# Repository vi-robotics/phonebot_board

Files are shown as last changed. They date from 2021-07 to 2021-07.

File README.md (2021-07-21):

# phonebot_board

The main PhoneBot electrical board containing servo control, regulator, charging and wireless capability.

This repository consists of two main components: design and firmware. The design folder contains the KiCAD design files, and the firmare folder contains the firmware meant to run on the design. Relevant documentation is located in each folder's README.md

- [Design](/design/README.md)
- [Firmware](/firmware/README.md)

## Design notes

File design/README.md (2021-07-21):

# Phonebot Board

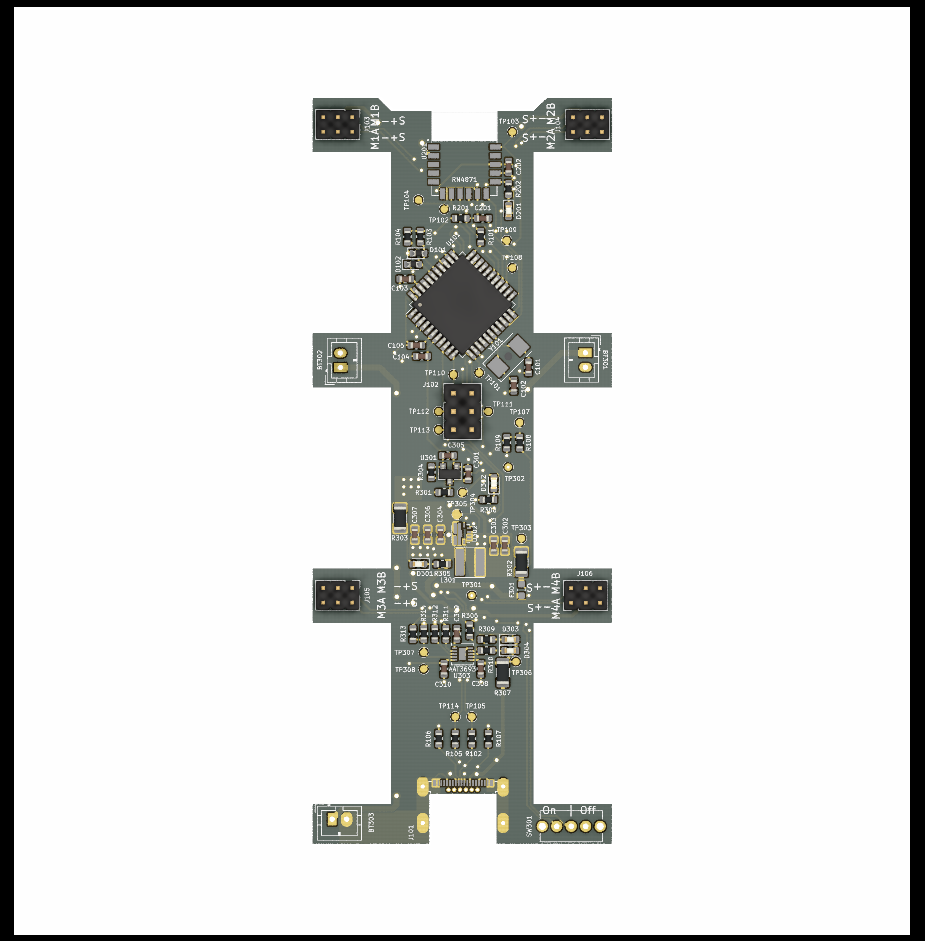
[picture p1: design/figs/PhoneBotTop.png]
Board


For detailed information on how to assemble PhoneBot, see the [electrical getting started](https://github.com/vi-robotics/phonebot_docs/blob/main/electrical/getting_started.md).

KiCad project for Phonebot electrical schematics and layout. There are two boards for PhoneBot

- [Main Board](main_board)
  - Contains the BLE coms module, AtMEGA32u4, and servo drivers
- [Servo Board](servo_board)
  - Convenience board to make servos replaceable without soldering on the main board

Design documents are availiable for the current release.

- [Schematics](figs/Schematics.pdf)
- [Layout](figs/Layout.pdf)

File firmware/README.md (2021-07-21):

# Embedded

Phonebot (Arduino) embedded developments, including firmware and sample apps.

## Running

The main firmware is located in the [firmware directory](firmware) and contains a `.ino` file which is runnable by the Arduino IDE as well as additional `.cpp` and `.h` files. For detailed instructions on how to install Arduino and flash the firmware, see [the docs](https://github.com/vi-robotics/phonebot_docs/blob/main/electrical/firmware_setup.md). Additional apps are located in the [apps directory](apps), and each sudirectory contains a `.ino` file which can be loaded onto PhoneBot using the same setup as described in the docs.

## Firmware

See the [firmware](firmware) directory, which contains our main firmware library to communicate with the PhoneBot App.

## Apps

Additional apps exist for testing small pieces of the hardware. Each contains a `.ino` file which can be opened by the Arduino IDE and flashed in the same way as the firmware.

- [calibrate](apps/calibrate): App for servo axis direction and zero-position calibration.
- [test_ble](apps/test_ble): Sample app for testing the BLE communication over serial.
- [test_walk](apps/test_walk): Test script for continuous walking trajectory.

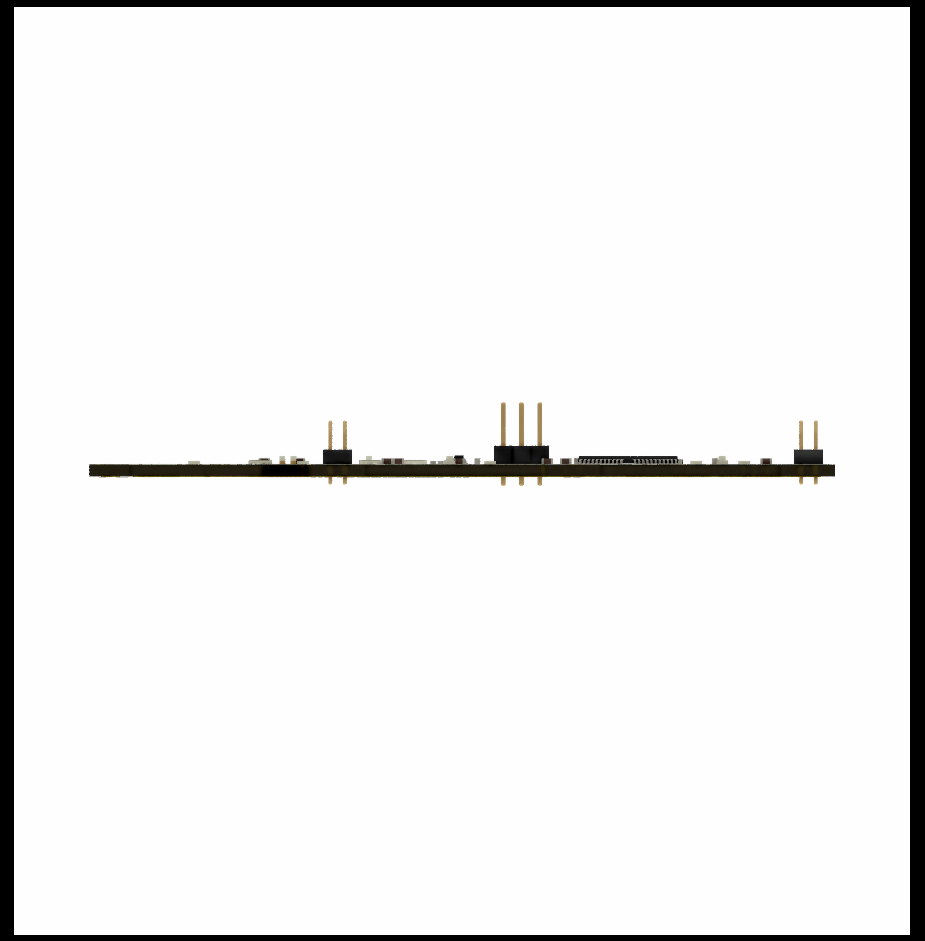
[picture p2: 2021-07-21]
design/figs/PhoneBotRight.png

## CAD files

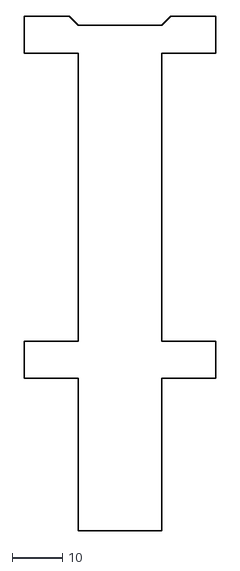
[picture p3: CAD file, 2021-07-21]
design/main_board/PCB_Outline.dxf
38.3 x 102.9

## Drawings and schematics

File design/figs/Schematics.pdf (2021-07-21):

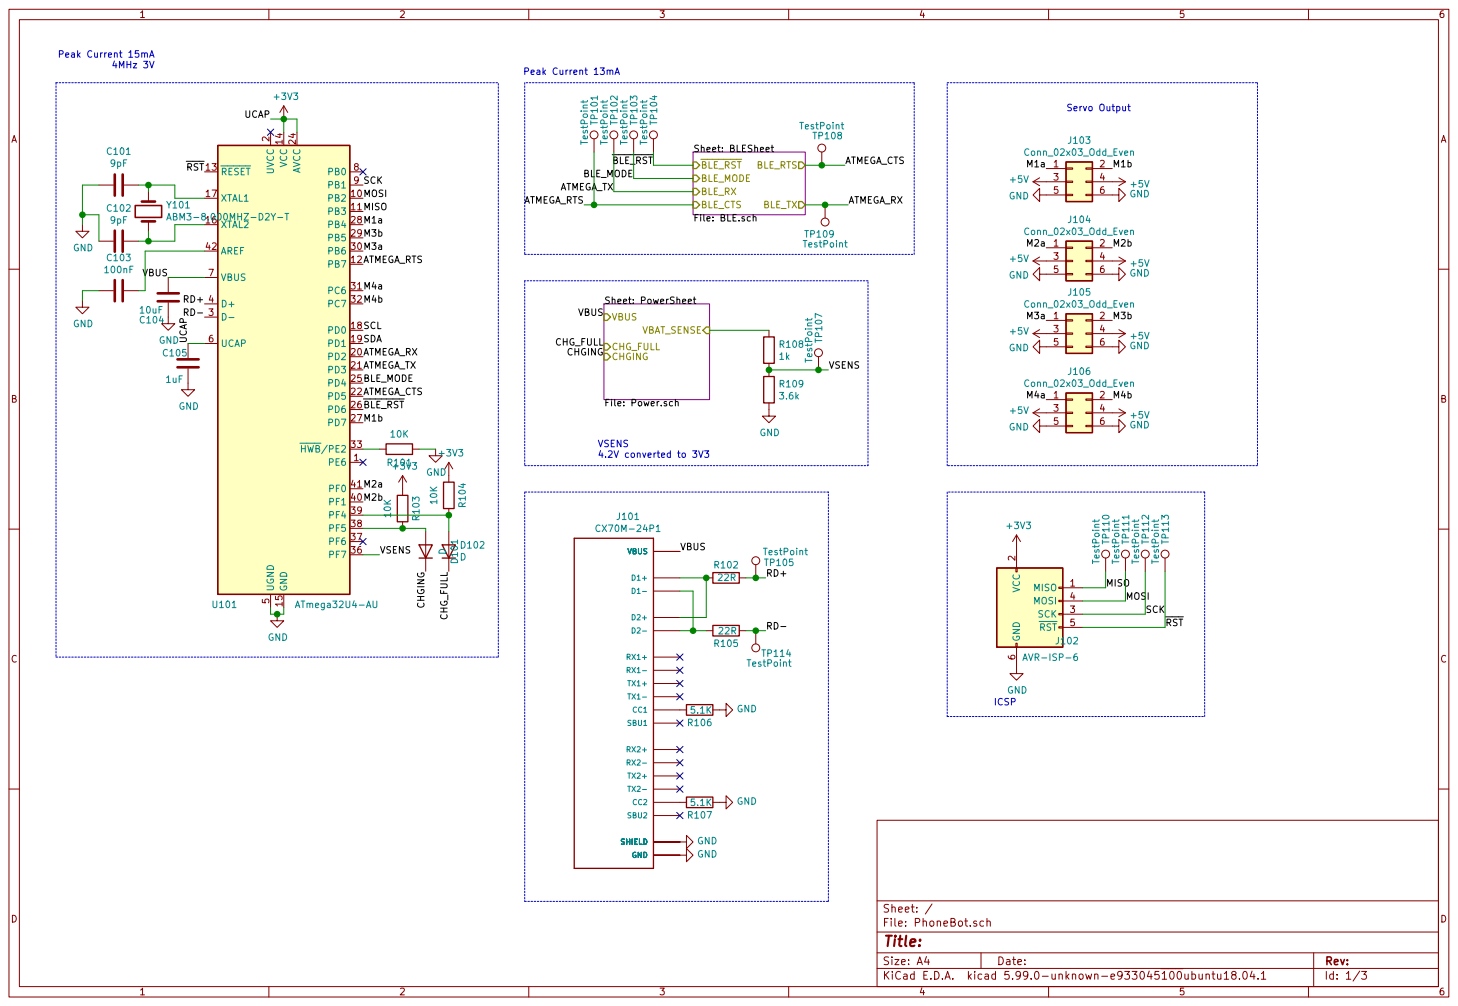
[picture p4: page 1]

4.2V converted to 3V3 Peak Current 13mA
Servo Output VSENS

2 PD2 20 PD3 21 PD5 22 AVCC 24 PD4 25 PD6 26 PD7 27 PB4 28 PB5 29 D- 3 PB6 30 PC6 31 PC7 32 HWB/PE2 33 PF7 36 PF6 37 PF5 38 PF4 39 D+ 4 PF1 40 PF0 41 AREF 42 UGND

Sheet: BLESheet File: BLE.sch BLE_MODE

Sheet: PowerSheet File: Power.sch VBUS
1k GND

2 SCK 3 MOSI 4 RST 5 GND

Id: 1/3 Title: File: PhoneBot.sch Sheet: /

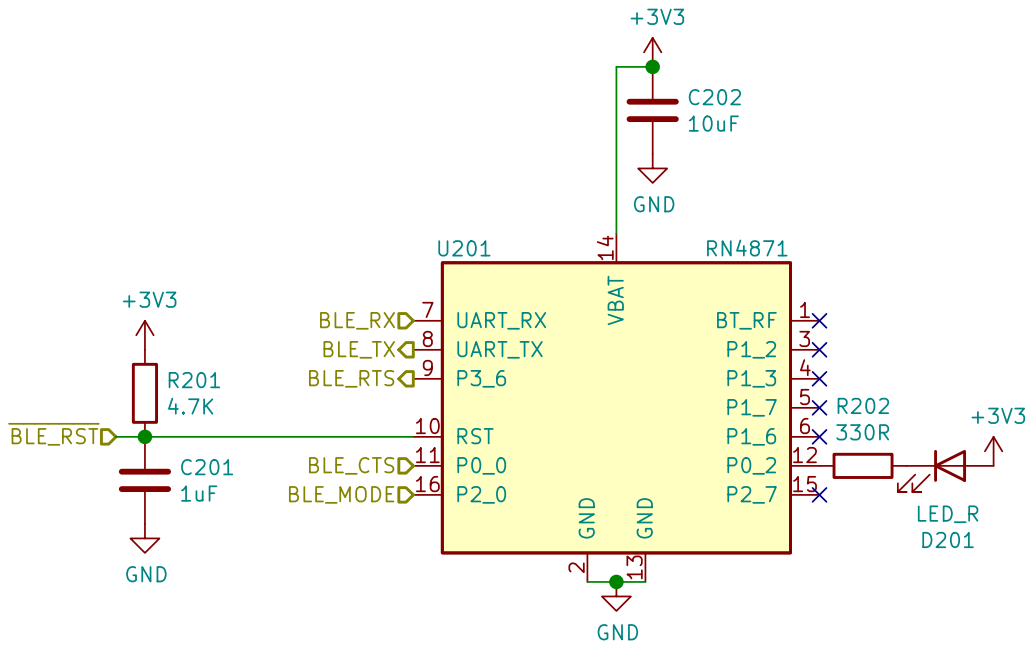
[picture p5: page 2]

Id: 2/3 Title: File: BLE.sch Sheet: /BLESheet/ GND

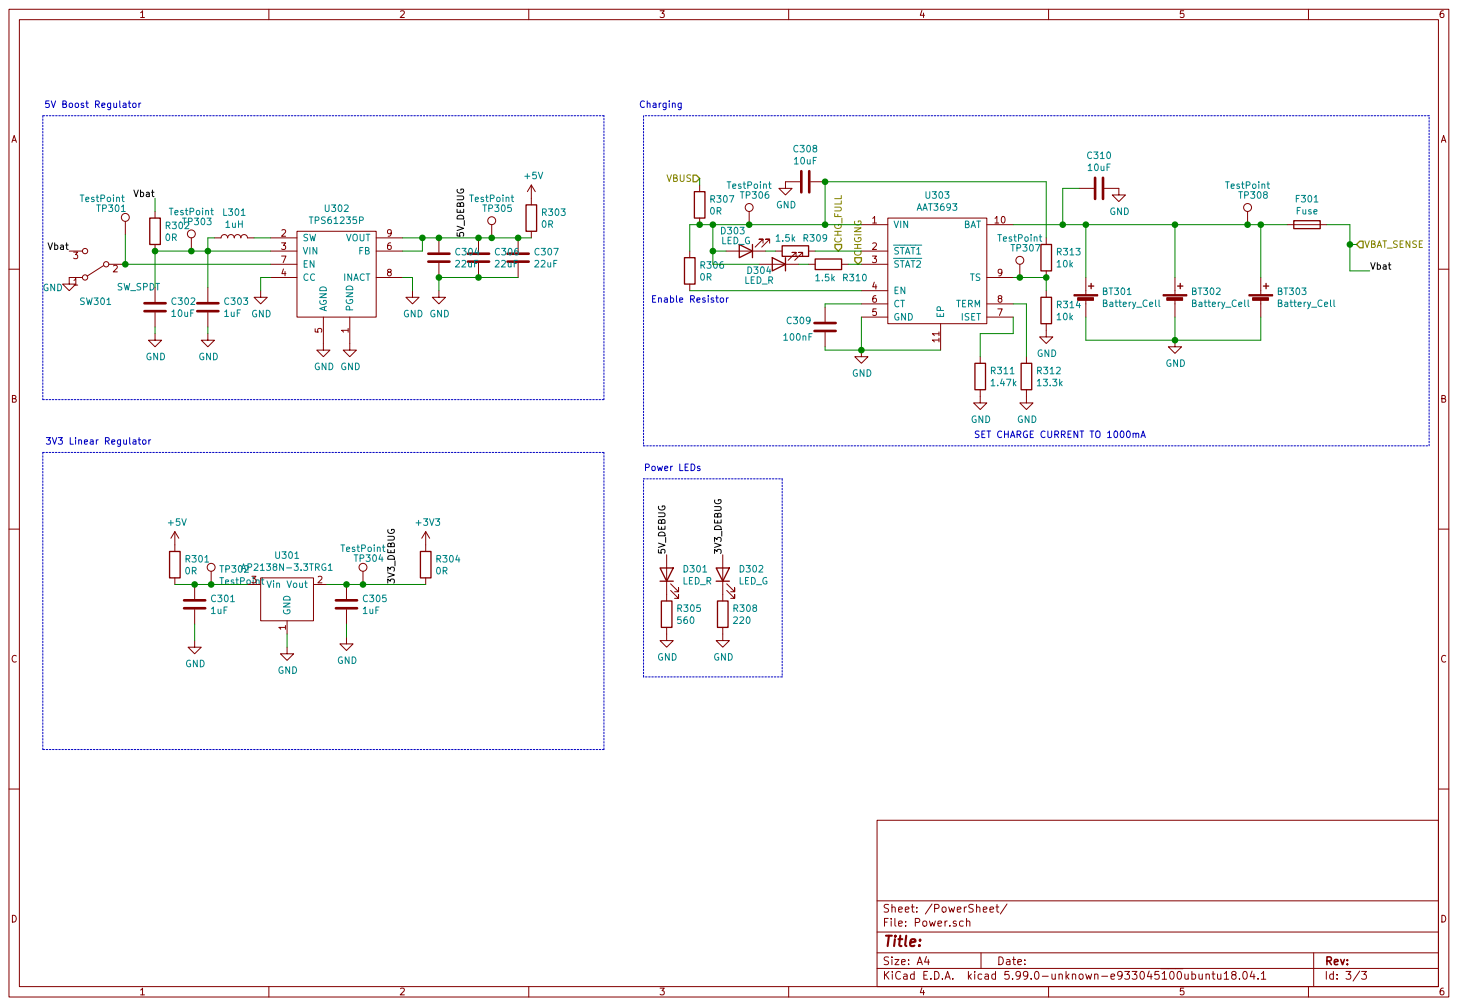
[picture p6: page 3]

Power LEDs Enable Resistor

1 SW 2 VIN 3 CC 4 AGND

1 Vout 2 Vin 3 U301 AP2138N-3.3TRG1 GND GND

Id: 3/3 Title: File: Power.sch Sheet: /PowerSheet/

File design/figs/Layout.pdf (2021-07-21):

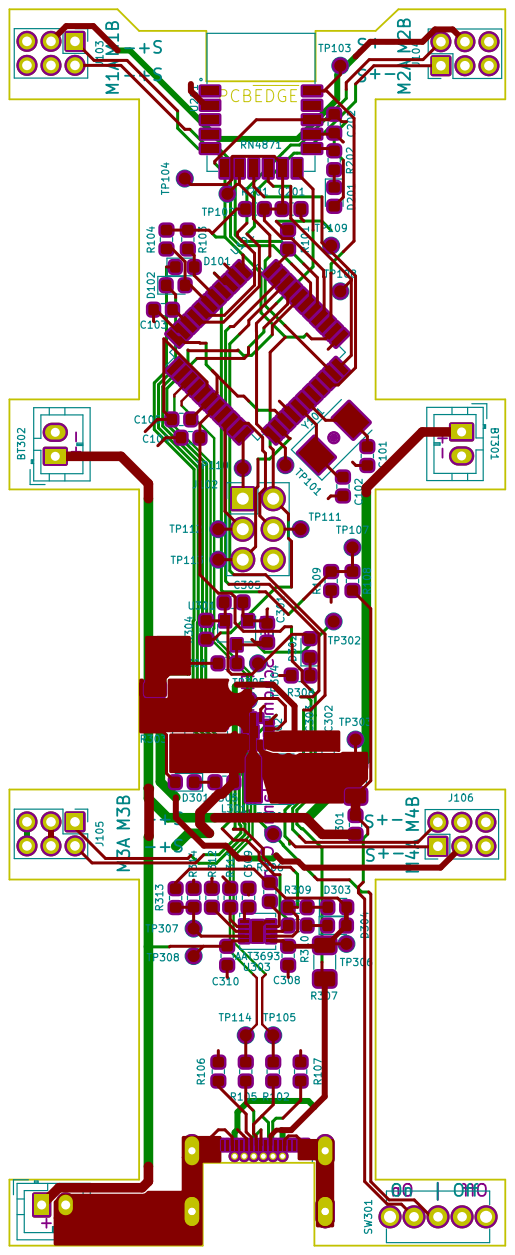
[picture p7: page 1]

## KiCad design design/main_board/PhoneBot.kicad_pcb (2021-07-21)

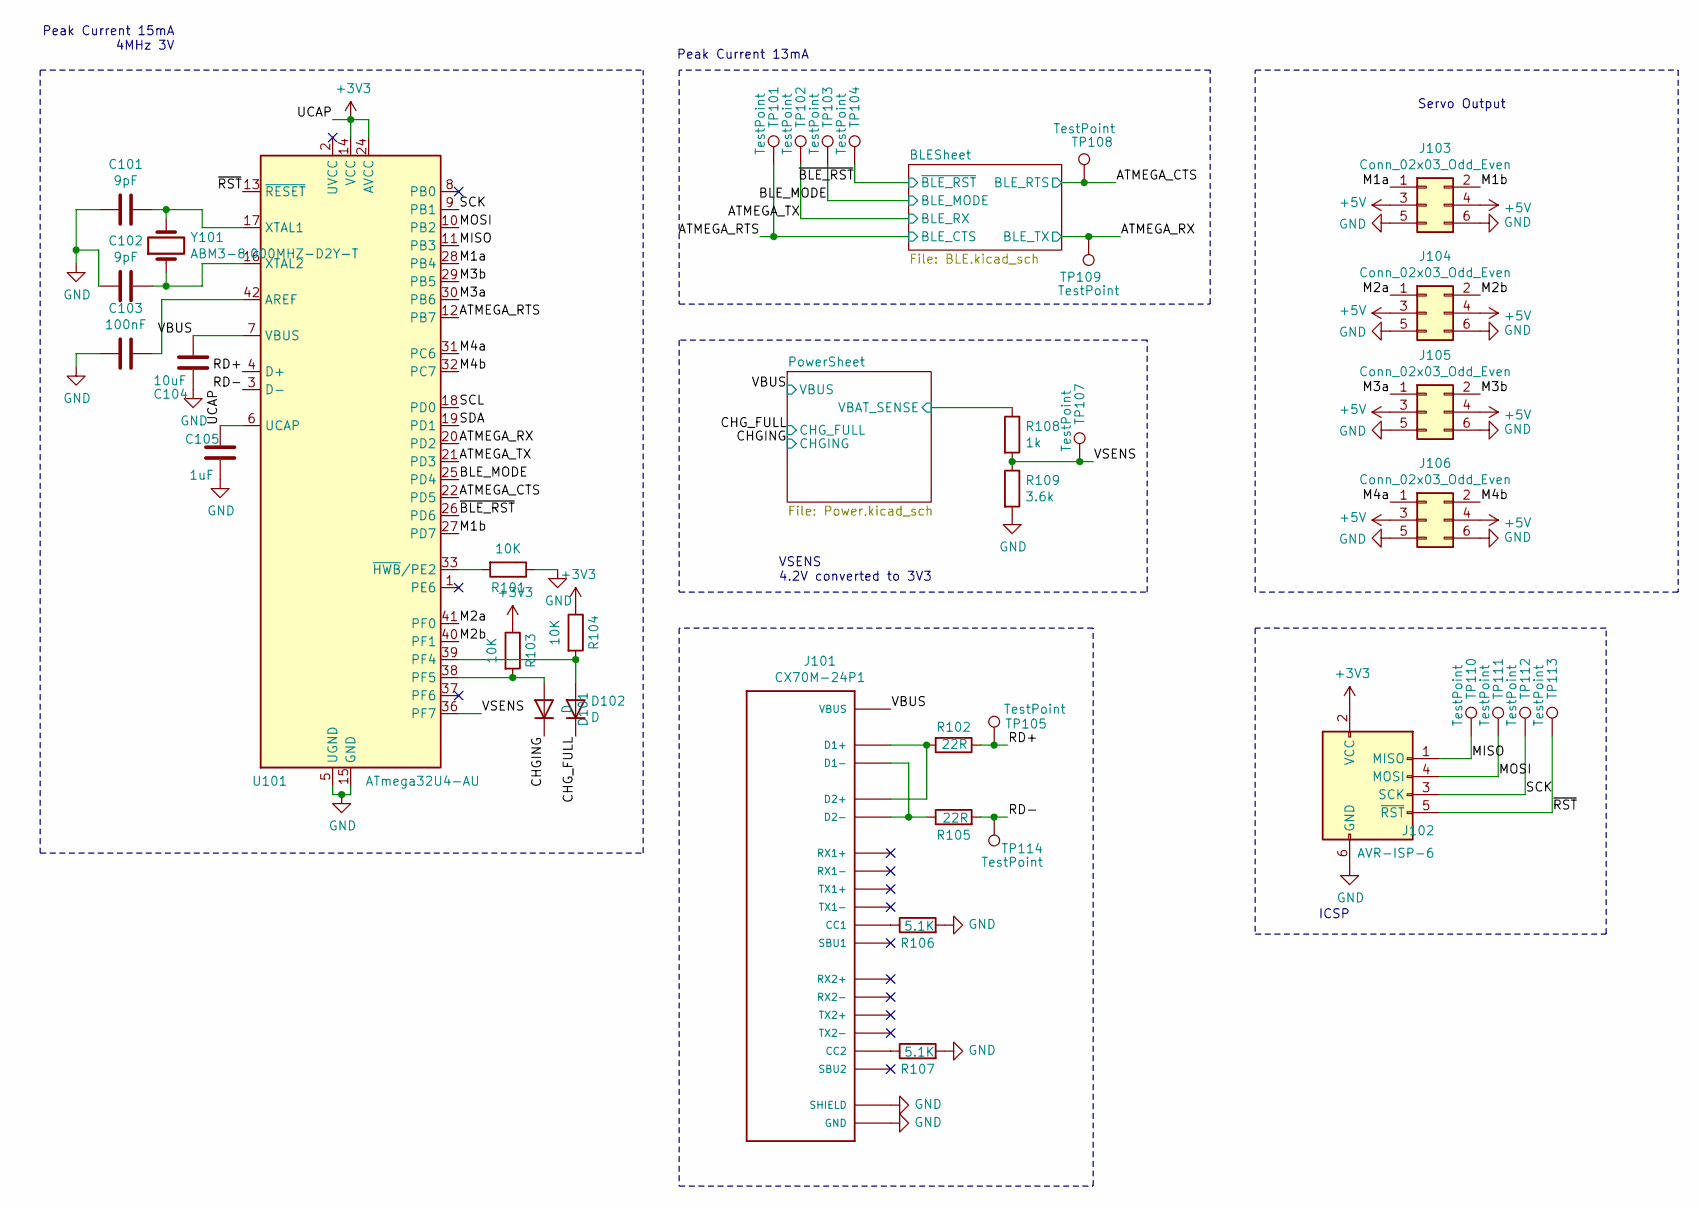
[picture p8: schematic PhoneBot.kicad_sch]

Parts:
C101, C102: 9pF; C_0603_1608Metric
C103: 100nF; C_0603_1608Metric
C104: 10uF; C_0603_1608Metric
C105: 1uF; C_0603_1608Metric
D101, D102: D; D_0603_1608Metric
J101: CX70M-24P1; HRS_CX70M-24P1
J102: AVR-ISP-6; PinHeader_2x03_P2.54mm_Vertical
J103, J104, J105, J106: Conn_02x03_Odd_Even; PinHeader_2x03_P2.00mm_Vertical
R101, R103, R104: 10K; R_0603_1608Metric
R102, R105: 22R; R_0603_1608Metric
R106, R107: 5.1K; R_0603_1608Metric
R108: 1k; R_0603_1608Metric
R109: 3.6k; R_0603_1608Metric
TP101, TP102, TP103, TP104, TP105, TP107, TP108, TP109, TP110, TP111, TP112, TP113, TP114: TestPoint; TestPoint_Pad_D1.0mm
U101: ATmega32U4-AU; TQFP-44_10x10mm_P0.8mm
Y101: ABM3-8.000MHZ-D2Y-T; Crystal_SMD_Abracon_ABM3-2Pin_5.0x3.2mm

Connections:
+3V3: C105.2, J102.2 (VCC), R103.1, R104.1, U101.6 (UCAP), U101.14 (VCC), U101.24 (AVCC), U101.34 (VCC), U101.44 (AVCC); also elsewhere on the board
+5V: J103.3, J103.4, J104.3, J104.4, J105.3, J105.4, J106.3, J106.4; also elsewhere on the board
/ATMEGA_CTS: TP108.1, U101.22 (PD5); also elsewhere on the board
/ATMEGA_RTS: TP101.1, U101.12 (PB7); also elsewhere on the board
/ATMEGA_RX: TP109.1, U101.20 (PD2); also elsewhere on the board
/ATMEGA_TX: TP102.1, U101.21 (PD3); also elsewhere on the board
/BLE_MODE: TP103.1, U101.25 (PD4); also elsewhere on the board
/CHGING: D101.1 (K); also elsewhere on the board
/CHG_FULL: D102.1 (K); also elsewhere on the board
/M1a: J103.1, U101.28 (PB4)
/M1b: J103.2, U101.27 (PD7)
/M2a: J104.1, U101.41 (PF0)
/M2b: J104.2, U101.40 (PF1)
/M3a: J105.1, U101.30 (PB6)
/M3b: J105.2, U101.29 (PB5)
/M4a: J106.1, U101.31 (PC6)
/M4b: J106.2, U101.32 (PC7)
/MISO: J102.1 (MISO), TP110.1, U101.11 (PB3)
/MOSI: J102.4 (MOSI), TP111.1, U101.10 (PB2)
/RD+: R102.1, TP105.1, U101.4 (D+)
/RD-: R105.2, TP114.1, U101.3 (D-)
/SCK: J102.3 (SCK), TP112.1, U101.9 (PB1)
/VBAT_SENSE: R108.1; also elsewhere on the board
/VBUS: C104.2, J101.A4 (VBUS), J101.A9 (VBUS), J101.B4 (VBUS), J101.B9 (VBUS), U101.7 (VBUS); also elsewhere on the board
/VSENS: R108.2, R109.1, TP107.1, U101.36 (PF7)
/~BLE_RST: TP104.1, U101.26 (PD6); also elsewhere on the board
/~RST: J102.5 (~RST), TP113.1, U101.13 (~RESET~)
GND: C101.1, C102.2, C103.2, C104.1, C105.1, J101.A1 (GND), J101.A12 (GND), J101.B1 (GND), J101.B12 (GND), J101.S1 (SHIELD), J101.S2 (SHIELD), J101.S3 (SHIELD), J101.S4 (SHIELD), J101.S5 (SHIELD), J101.S5.1 (SHIELD), J101.S6 (SHIELD), J101.S6.1 (SHIELD), J102.6 (GND), J103.5, J103.6, J104.5, J104.6, J105.5, J105.6, J106.5, J106.6, R101.1, R106.2, R107.2, R109.2, U101.5 (UGND), U101.15 (GND), U101.23 (GND), U101.35 (GND), U101.43 (GND); also elsewhere on the board
unnamed: C101.2, U101.17 (XTAL1), Y101.2
unnamed: C102.1, U101.16 (XTAL2), Y101.1
unnamed: C103.1, U101.42 (AREF)
unnamed: D101.2 (A), R103.2, U101.38 (PF5)
unnamed: D102.2 (A), R104.2, U101.39 (PF4)
unnamed: J101.A5 (CC1), R106.1
unnamed: J101.A6 (D1+), J101.B6 (D2+), R102.2
unnamed: J101.A7 (D1-), J101.B7 (D2-), R105.1
unnamed: J101.B5 (CC2), R107.1
unnamed: R101.2, U101.33 (~HWB~/PE2)

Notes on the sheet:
Peak Current 15mA 4MHz 3V
VSENS 4.2V converted to 3V3
Peak Current 13mA
ICSP
Servo Output

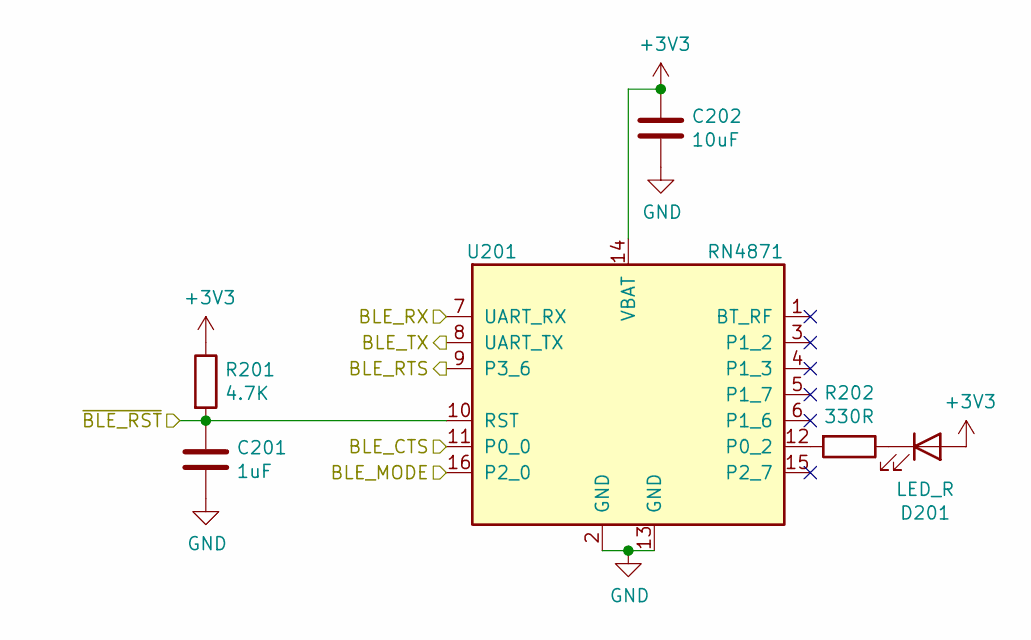
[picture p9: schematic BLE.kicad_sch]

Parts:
C201: 1uF; C_0603_1608Metric
C202: 10uF; C_0603_1608Metric
D201: LED_R; LED_0603_1608Metric
R201: 4.7K; R_0603_1608Metric
R202: 330R; R_0603_1608Metric
U201: RN4871; XCVR_RN4871-V%2fRM118

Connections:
+3V3: C202.1, D201.2 (A), R201.1, U201.14 (VBAT); also elsewhere on the board
/ATMEGA_CTS: U201.9 (P3_6); also elsewhere on the board
/ATMEGA_RTS: U201.11 (P0_0); also elsewhere on the board
/ATMEGA_RX: U201.8 (UART_TX); also elsewhere on the board
/ATMEGA_TX: U201.7 (UART_RX); also elsewhere on the board
/BLE_MODE: U201.16 (P2_0); also elsewhere on the board
/~BLE_RST: C201.1, R201.2, U201.10 (RST); also elsewhere on the board
GND: C201.2, C202.2, U201.2 (GND), U201.13 (GND); also elsewhere on the board
unnamed: D201.1 (K), R202.1
unnamed: R202.2, U201.12 (P0_2)

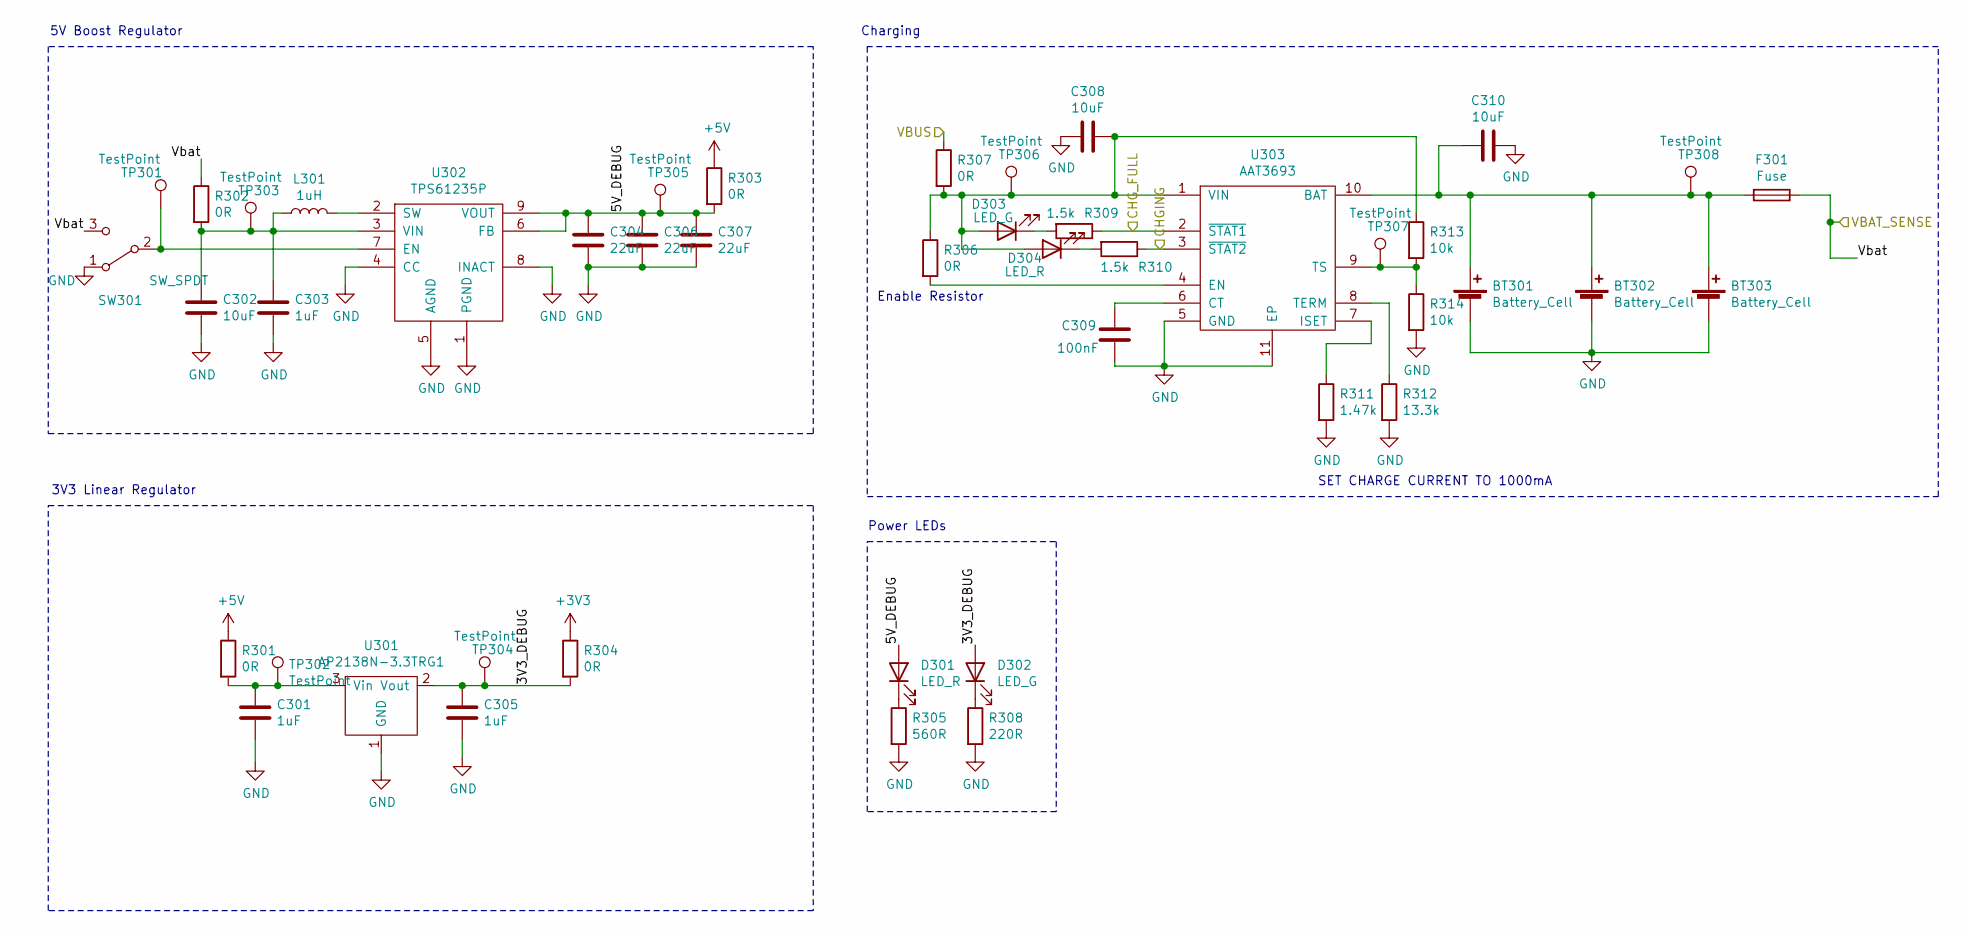
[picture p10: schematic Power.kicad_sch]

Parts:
BT301, BT302, BT303: Battery_Cell; JST_PH_B2B-PH-K_02x2.00mm_Straight
C301, C303, C305: 1uF; C_0603_1608Metric
C302, C308, C310: 10uF; C_0603_1608Metric
C304, C306, C307: 22uF; C_0603_1608Metric
C309: 100nF; C_0603_1608Metric
D301, D304: LED_R; LED_0603_1608Metric
D302, D303: LED_G; LED_0603_1608Metric
F301: Fuse; Fuse_0603_1608Metric
L301: 1uH; L_Taiyo-Yuden_MD-4040
R301, R304, R306: 0R; R_0603_1608Metric
R302, R303, R307: 0R; R_1206_3216Metric
R305: 560R; R_0603_1608Metric
R308: 220R; R_0603_1608Metric
R309, R310: 1.5k; R_0603_1608Metric
R311: 1.47k; R_0603_1608Metric
R312: 13.3k; R_0603_1608Metric
R313, R314: 10k; R_0603_1608Metric
SW301: SW_SPDT; SW_SPDT_1825232
TP301, TP302, TP303, TP304, TP305, TP306, TP307, TP308: TestPoint; TestPoint_Pad_D1.0mm
U301: AP2138N-3.3TRG1; SOT-23
U302: TPS61235P; TPS61235PRWLT
U303: AAT3693

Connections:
+3V3: R304.1; also elsewhere on the board
+5V: R301.1, R303.1; also elsewhere on the board
/CHGING: R310.1, U303.3 (~STAT2); also elsewhere on the board
/CHG_FULL: R309.1, U303.2 (~STAT1); also elsewhere on the board
/PowerSheet/3V3_DEBUG: C305.1, D302.2 (A), R304.2, TP304.1, U301.2 (Vout)
/PowerSheet/5V_DEBUG: C304.1, C306.1, C307.1, D301.2 (A), R303.2, TP305.1, U302.6 (FB), U302.9 (VOUT)
/VBAT_SENSE: F301.1, R302.1, SW301.3 (C); also elsewhere on the board
/VBUS: R307.1; also elsewhere on the board
GND: BT301.2 (-), BT302.2 (-), BT303.2 (-), C301.2, C302.2, C303.2, C304.2, C305.2, C306.2, C307.2, C308.2, C309.2, C310.1, R305.2, R308.2, R311.2, R312.2, R314.2, SW301.1 (A), U301.1 (GND), U302.1 (PGND), U302.4 (CC), U302.5 (AGND), U302.8 (INACT), U303.5 (GND), U303.11 (EP); also elsewhere on the board
unnamed: BT301.1 (+), BT302.1 (+), BT303.1 (+), C310.2, F301.2, TP308.1, U303.10 (BAT)
unnamed: C301.1, R301.2, TP302.1, U301.3 (Vin)
unnamed: C302.1, C303.1, L301.1, R302.2, TP303.1, U302.3 (VIN)
unnamed: C308.1, D303.2 (A), D304.2 (A), R306.1, R307.2, R313.1, TP306.1, U303.1 (VIN)
unnamed: C309.1, U303.6 (CT)
unnamed: D301.1 (K), R305.1
unnamed: D302.1 (K), R308.1
unnamed: D303.1 (K), R309.2
unnamed: D304.1 (K), R310.2
unnamed: L301.2, U302.2 (SW)
unnamed: R306.2, U303.4 (EN)
unnamed: R311.1, U303.7 (ISET)
unnamed: R312.1, U303.8 (TERM)
unnamed: R313.2, R314.1, TP307.1, U303.9 (TS)
unnamed: SW301.2 (B), TP301.1, U302.7 (EN)

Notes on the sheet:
5V Boost Regulator
3V3 Linear Regulator
Power LEDs
Charging
Enable Resistor
SET CHARGE CURRENT TO 1000mA

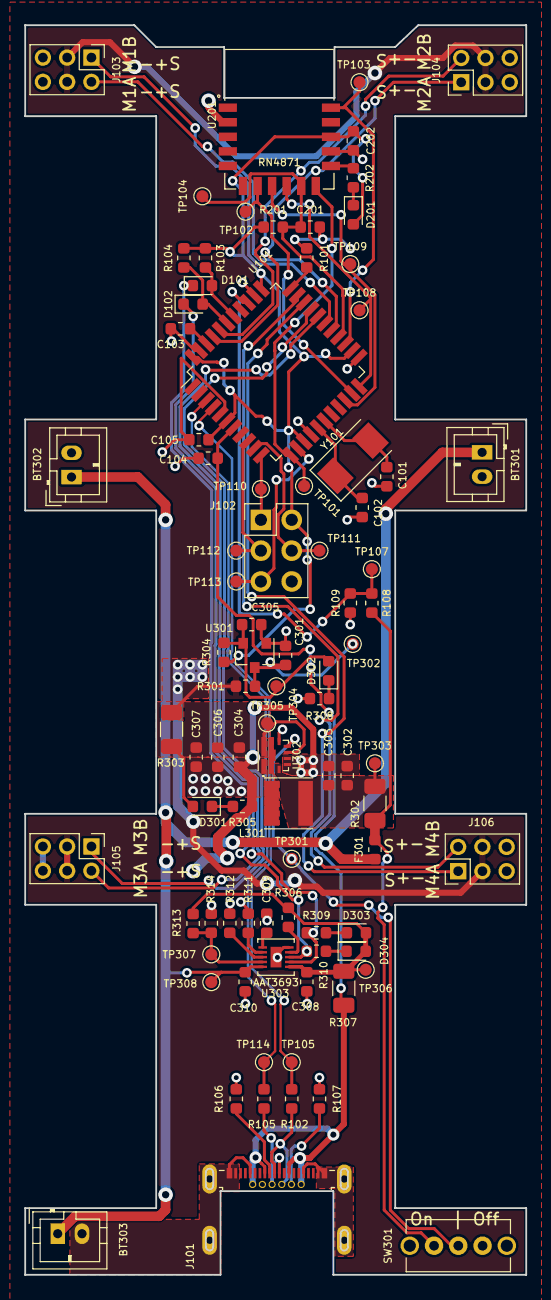
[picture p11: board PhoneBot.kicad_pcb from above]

Board: 2 copper layers, 41.3 x 103.0 mm, 88 parts (0 on the bottom side), 57 nets.

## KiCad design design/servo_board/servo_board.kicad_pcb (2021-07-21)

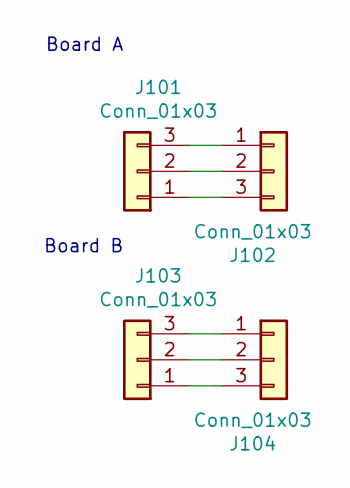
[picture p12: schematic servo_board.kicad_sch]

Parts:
J101, J103: Conn_01x03; PinHeader_1x03_P2.00mm_Horizontal
J102, J104: Conn_01x03; PinHeader_1x03_P2.00mm_Vertical

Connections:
unnamed: J101.1, J102.3
unnamed: J101.2, J102.2
unnamed: J101.3, J102.1
unnamed: J103.1, J104.3
unnamed: J103.2, J104.2
unnamed: J103.3, J104.1

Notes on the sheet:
Board A
Board B

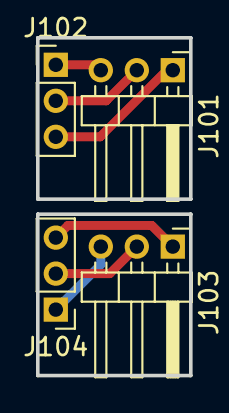
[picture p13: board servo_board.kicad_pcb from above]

Board: 2 copper layers, 8.5 x 18.8 mm, 4 parts (0 on the bottom side), 6 nets.

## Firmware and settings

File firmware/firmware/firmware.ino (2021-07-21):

/**
 * @file firmware.ino
 * @author Maximilian Schommer (maxschommer@gmail.com)
 * @brief PhoneBot firmware manages BLE communications and executing commands
 * sent over BLE.
 * @version 0.1
 * @date 2021-05-11
 *
 * @copyright Copyright (c) 2021
 *
 */
#include "phonebot.h"

PhoneBot bot;

/**
 * @brief Starts up PhoneBot
 *
 */
void setup() {
  bot.begin();
}

/**
 * @brief Runs the update loop of PhoneBot
 *
 */
void loop() {
  bot.step();
}

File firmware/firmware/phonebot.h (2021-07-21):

/**
 * @file phonebot.h
 * @author Maximilian Schommer (maxschommer@gmail.com)
 * @brief PhoneBot class monitors and responds to BLE serial events
 * @version 0.1
 * @date 2021-05-11
 *
 * @copyright Copyright (c) 2021
 *
 */
#ifndef __PHONEBOT_H__
#define __PHONEBOT_H__

#include "common.h"
#include "command_interpreter.h"
#include "ble.h"

 /*
    PIN MAPPINGS
     (US)
     M1a , M1b , M2a , M2b , M3a , M3b , M4a , M4b
     PB4 , PD7 , PF0 , PF1 , PB6 , PB5 , PC6 , PC7
     (Physical Pin Number)
     28  , 27  , 41  , 40  , 30  , 29  , 31  , 32
     (Sparkfun)
     D8  , D6  , D23 , D22 , D10 , D9  , D5  , D13 // << use this since we're using their board definition
 */


 /**
  * @brief PhoneBot manages servo control and BLE communication
  *
  */
class PhoneBot
{
   int pins_[NUM_JOINTS] = { 8, 6, 23, 22, 10, 9, 5, 13 };

   // Initialize it with the default pins by default
   CommandInterpreter command_interpreter = CommandInterpreter(pins_);

   // communication
   BLE ble_;

   int positions_[NUM_JOINTS];

public:

   /**
      @brief Constructs a PhoneBot which is bound to the default pins
   */
   PhoneBot(); // Default constructor uses above pins if none are provided

   /**
      @brief Constructs a PhoneBot which is bound to the provided pins

      @param pins The pins to bind to for each leg. Must contain 8 elements
   */
   PhoneBot(const int* pins);

   /**
    * @brief Starts BLE communication
    */
   void begin();


   /**
    * @brief Handles BLE receive and transmit buffers as well as
    * interpreting data sent over BLE and executing it via the
    * command interpreter.
    */
   void step();
};

#endif

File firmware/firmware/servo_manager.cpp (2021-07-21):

/**
 * @file servo_manager.cpp
 * @author Maximilian Schommer (maxschommer@gmail.com)
 * @brief ServoManager and ServoController manage servos in an energy efficient
 * way by detaching from the servo pin when a timeout has been exceeded.
 * @version 0.1
 * @date 2021-05-11
 *
 * @copyright Copyright (c) 2021
 *
 */
#include <Arduino.h>
#include "servo_manager.h"


ServoController::ServoController(const int pin, int timeout = 100) {
    pin_ = pin;
    timeout_ = timeout;
    pinMode(pin_, OUTPUT);
}


void ServoController::step()
{

    // In this condition, the servo should always be attached
    // and timer reset.
    if (old_value_ != new_value_)
    {
        if (!is_attached)
        {
            servo_.attach(pin_);
            is_attached = true;
        }
        servo_.write(new_value_);
        last_updated = millis();
        old_value_ = new_value_;
    }
    else
    {
        if (millis() - last_updated > timeout_)
        {
            if (is_attached)
            {
                servo_.detach();
                is_attached = false;
            }
        }
    }
}

void ServoController::setPosition(int val)
{
    old_value_ = new_value_;
    new_value_ = constrain(val, 0, 180);
    step();
}

ServoManager::ServoManager(const int* pins, const int num_pins, int timeout = 100)
{
    num_pins_ = num_pins;

    // Avoids the need for a default constructor for the ServoController class
    // Uses array of pointers
    servo_controllers_ = new ServoController * [num_pins]; // TODO(Max): Figure out how to get rid of new.
    for (int i = 0; i < num_pins; ++i)
    {
        servo_controllers_[i] = new ServoController(pins[i], timeout); // TODO(Max): Figure out how to get rid of new.
    }
}

void ServoManager::step()
{
    for (int i = 0; i < num_pins_; i++)
    {
        servo_controllers_[i]->step();
    }
}

void ServoManager::setPositions(const byte* const vals)
{
    for (int i = 0; i < num_pins_; i++)
    {
        servo_controllers_[i]->setPosition(vals[i]);
    }
}

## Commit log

2021-04-03 Added servo board
    [BLE.kicad_sch, PCB_Outline.dxf, PhoneBot.kicad_pcb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]
2021-05-12 Reformatted files according to Arduino's preferences
2021-05-12 Made comments consistent, broke all lone header files into header and cpp files
    [ble.h, command_interpreter.h, firmware.ino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]
2021-05-12 Added file header to servo_manager
